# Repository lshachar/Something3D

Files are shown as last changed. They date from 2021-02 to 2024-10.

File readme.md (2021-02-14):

Check out this very detailed video I made [here](https://youtu.be/JVCmWvRvEYM).  
(It's in Hebrew... I Don't think anyone outside of Israel have ever heard about this 3D printer company.)  
I bought mine in 2013 and it worked awfully until 2021, when I fixed all the issues it had.  
The purpose of this git is to help owners of a Something3D printer to make it into a usable machine!    

If you'd like to update your Marlin Firmware, and use my settings,  
Download [Marlin 2.0.1](https://github.com/MarlinFirmware/Marlin/releases/tag/2.0.1)  
Use my Configuration.h & Configuration_adv.h files.

If you'd like to use a newer Marlin you can compare (diff) these two files on this github,  
to their original version that you have downloaded.  
Then download a newer Marlin firmware, and edit the two new files with all the necessary changes from my files.

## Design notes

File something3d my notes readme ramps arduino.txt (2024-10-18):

Something3D
02:28 ‎08/‎05/‎2023
בבדיקה עם
PID_OPENLOOP
בכוח מלא (255, שמשום מה מציג לי שהוא מעביר 245)
בגובה 7.5ממ אני מצליח להגיע לטמפ' 210 מעלות, עם מאוורר על 100 אחוז, אבל לא תוך כדי הוצאת פלסטיק.
אז אני מגביל בפרופיל את המאוורר ל80 אחוז בגובה 7.5
(ציפיתי את הראש החם בשכבת סיליקון היום בבוקר)
___________
Parts:

Ramps V1.4 (can be read on board)
screen + sd card reader mj204b (RAMPS GADGETS3D LCD and SHIELD v1.0) http://gadgets3d.com/beta/index.php?route=product/product&product_id=65
gadgets3d fan splitter rev1
Arduino mega 2560
installed stepper motor drivers, on Ramps board: G3D A498 driver rev1
hotbed thermocoupler resistence: 142.7 kOhm
Nozzle on both = 0.35 (according to an old slic3r file from 2013, probably legit)

X max travel 280
Y max travel 270 (but can actually reach 280, if I really need it one day...)
Z max travel 270

3/4 extruder motors: sy42sth47 1206A (except Z)
(060047083 & 1806307 is still also readable on them)

____________

Original Firmware settings:
Control->Temperature
Autotemp off
	Min:210
	Max:250
	Fact:000.10
PID-P: +058.91
PID-I: +004.96
PID-D: +174.70
PID-C: 1

Control->Temperature->Preheat PLA conf
Fan speed:255	(i'm assuming this isn't wired)
Nozzle:200
Bed:60

Control->Temperature->Preheat ABS conf
Nozzle:235 (240 default for marlin firmware)
Bed:105 (110 default for marlin firmware)

Control->Motion
Accel:500
Vxy-jerk: 5
Vz-jerk: +000.10
Ve-jerk: 5
Vmax x: 500
Vmax y: 500
Vmax z: 5
Vmax e: 25
Vmin: 0
VTray min: 0
Amax x: 900
Amax y: 900
Amax z: 5
Amax e: 10000
A-retract: 900
Xsteps/mm: +053.20  ** new: 53.5
Ysteps/mm: +053.20  ** new: 53.5
Zsteps/mm: +1632.0  ** new: 1600
Esteps/mm: +0095.6  ** new: 92.73 for 1st (new) extruder, unknown for 2nd
updated Esteps to 94.18 on 4.5.23.

_____________
A few links that helped me:

https://3dprinting.stackexchange.com/questions/6535/controlling-more-fans-with-ramps-board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

UBL:
https://marlinfw.org/docs/features/unified_bed_leveling.html
https://3dprinting.stackexchange.com/questions/8153/how-to-set-z-probe-boundary-limits-in-firmware-when-using-automatic-bed-leveling
https://github.com/MarlinFirmware/Marlin/issues/9418 

_____________
Notes for self. Testing and calibrating my printer 29.1.2021
100mm at 50mm/min 2nd extruder (left) T1, extruded 105.3mm.
100mm at 50mm/min 1st extruder, extruded 98mm.
why?
anyhow current value is 95.6.
so let's print with 1st extruder, new value 97.551
https://www.e-ci.com/3d-scoop/2020/1/16/calculating-e-steps-extruder-accuracy-in-octoprint

Watching how the cel automaker prints: EVERY layer has a full grid infill. as oppose to: one layer criss, other layer cross. so adhesion must be better!!
Kisslicer is not willing to generate that!
(fill pattern is called 'lines' in automaker, but Cura calls it 'grid'. and it is using Cura for the gcode.

I'm overextruding while the printer is moving - then there's low pressure when it's starting to extrude again.
I can retract at every Z level change and then add 0.64 mm^3 (retraction extra prime amount - cura). looks better.
https://community.ultimaker.com/topic/15459-retraction-extra-prime-amount-suggested-values/

Z max feedrate at 10 was too much! went back to default 5!
50mm movement at Z gives me 51mm!
current steps:1632 per mm.
//fyi:
//10 threads are ~19.5mm
//1mm = 0.5128205128205128 = 1632of Z axis turn (~half a thread)
1632 * 50 / 51 = 1600. seems great!

fml. x axis 130mm was 129.3
053.20 * 130/129.3
new steps: 53.48. 53.5? works great. (assumed x/y are the same. for good reasons though)

new extruder assembly. 
now 100mm extrusion = 105.2, new 92.73, good.

20x20x5 cube *on CEL automaker*:
11.67 seconds for single parameter (hollow)
80/11.67 = 6.85 mm/s
30 seconds for the top layer. 
which is 50 stripes of 0.4mm extrusion. 50x20 = 1000mm total layer length.
1000/30 = 33mm/s for the top layer.

_____________
Some Gcode commands
http://marlinfw.org/meta/gcode/
g92 z0 set home
g90 absolute
g91 relative

g28 - auto home - watch out!
M114 - Get Current Position
M119 - Get endstop state
M211 - software endstops off/on
M226 - wait for pin State.

ניסיון שימוש בפקודה שמחכה ללחיצה על המיקרוסויץ' של הזד שלא עובדת כרגע:
G0 X0
M117 wait for z limit switch to get pressed  (only 20 letters on screen)
M226 P18 S1
G0 X5
M25 ; pause sd print
G0 x0

5.5.23, current m503:
SENDING:M503
echo:  G21    ; Units in mm (mm)
echo:  M149 C ; Units in Celsius
echo:Filament settings: Disabled
echo:  M200 D1.75
echo:  M200 T1 D1.75
echo:  M200 D0
echo:Steps per unit:
echo: M92 X53.50 Y53.50 Z1600.00 E94.18
echo:Maximum feedrates (units/s):
echo:  M203 X500.00 Y500.00 Z5.00 E500.00
echo:Maximum Acceleration (units/s2):
echo:  M201 X500.00 Y500.00 Z100.00 E10000.00
echo:Acceleration (units/s2): P<print_accel> R<retract_accel> T<travel_accel>
echo:  M204 P500.00 R2000.00 T3000.00
echo:Advanced: B<min_segment_time_us> S<min_feedrate> T<min_travel_feedrate> J<junc_dev>
echo:  M205 B20000.00 S0.00 T0.00 J0.01
echo:Home offset:
echo:  M206 X0.00 Y0.00 Z0.00
echo:Hotend offsets:
echo:  M218 T1 X33.30 Y0.00 Z0.000
echo:Unified Bed Leveling:
echo:  M420 S1 Z10.00
Unified Bed Leveling System v1.01 active
Active Mesh Slot: 1
EEPROM can hold 7 meshes.
echo:Material heatup parameters:
echo:  M145 S0 H195 B60 F0
echo:  M145 S1 H235 B105 F0
echo:PID settings:
echo:  M301 P161.35 I24.63 D264.29 F0.00
echo:  M301 P107.71 I13.55 D213.98 F0.00
echo:  M304 P73.68 I7.56 D478.84
echo:Z-Probe Offset (mm):
echo:  M851 X-44.00 Y-4.00 Z7.50
echo:Linear Advance:
echo:  M900 T0 K0.12
  M900 T1 K0.00
echo:Tool-changing:
echo: Z2.00

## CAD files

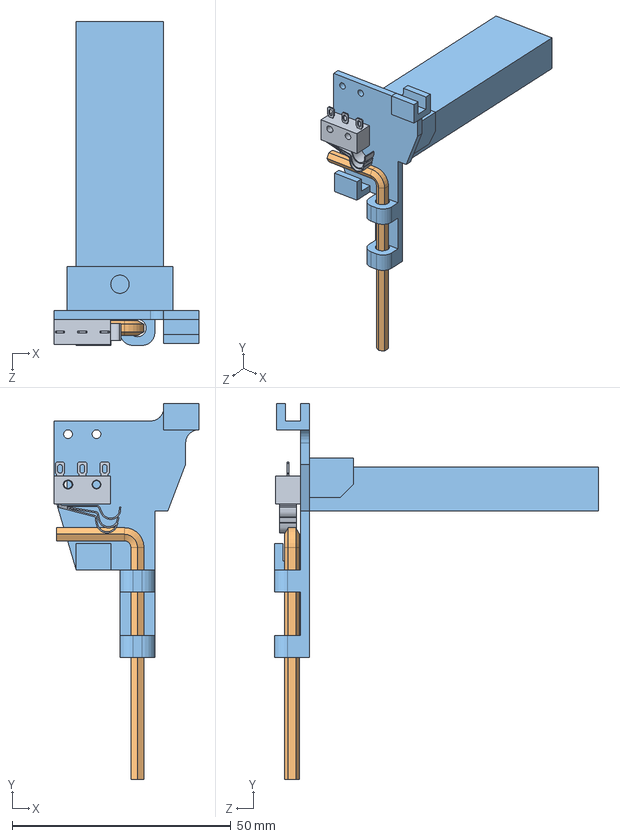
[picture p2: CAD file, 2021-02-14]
ABL Z-Probe/ABL allen.SLDASM
33.0 x 85.9 x 74.0 mm
Microswitch
3mm Allen^ABL allen
ABL stand^ABL allen

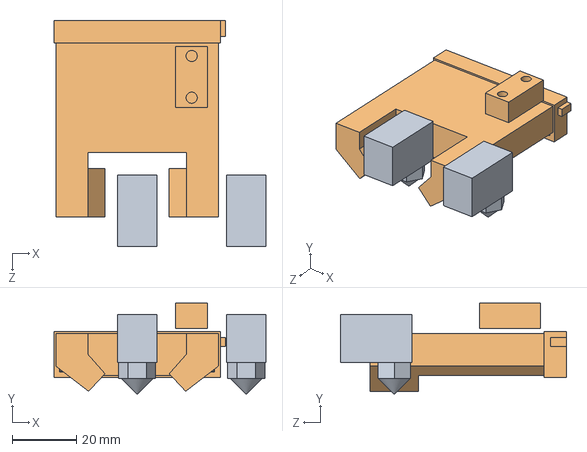
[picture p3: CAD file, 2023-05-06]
something3d fan mount/fan mount.SLDASM
66.1 x 28.3 x 70.3 mm
nozzle x 2
fan mount v4

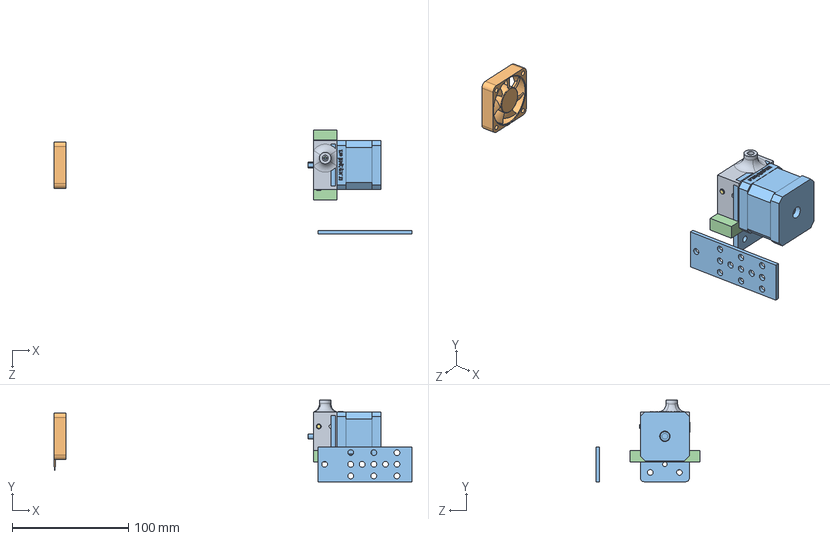
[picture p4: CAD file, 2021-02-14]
extruder v2/something 3d extruder.SLDASM
307.4 x 70.0 x 89.0 mm
Extruder case - v4
nema17 motor
metal bar^something 3d extruder
624z bearing^something 3d extruder
extruder lever - straight V2
hex bolt gradeab_iso

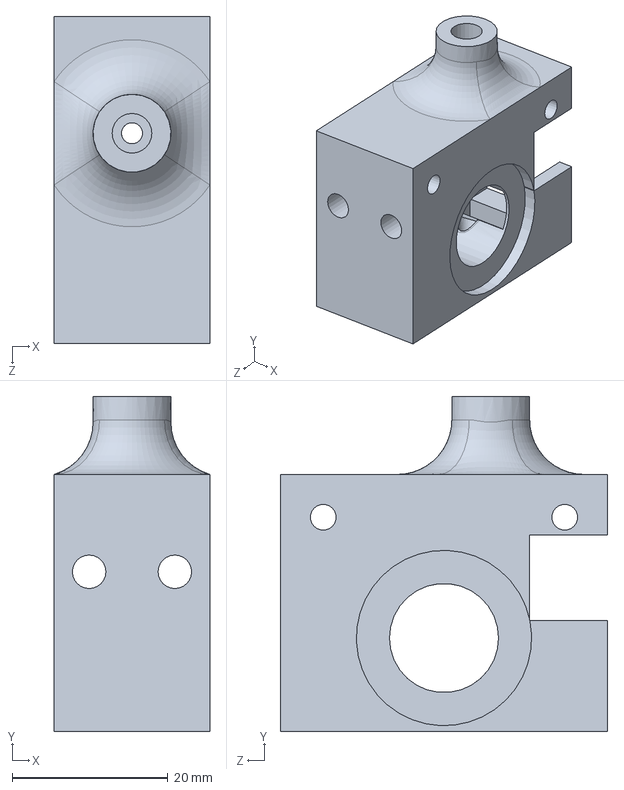
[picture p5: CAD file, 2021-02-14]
extruder v2/Extruder case - v4.SLDPRT
20.0 x 43.0 x 42.0 mm

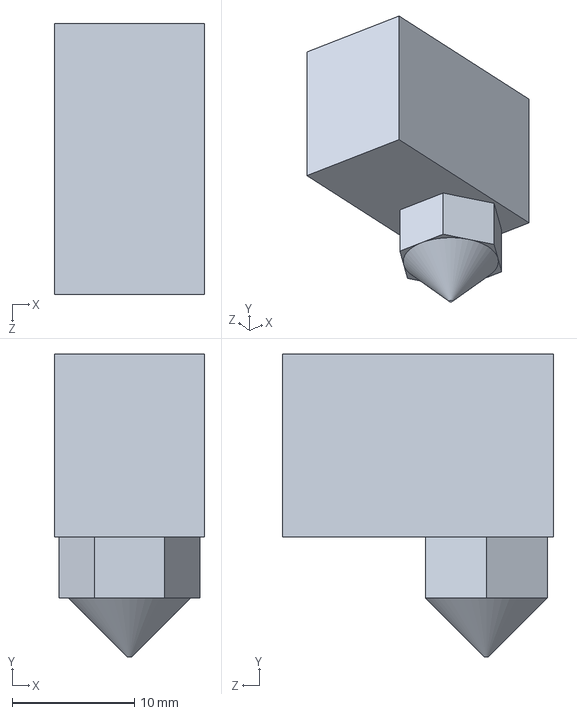
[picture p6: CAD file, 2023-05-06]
something3d fan mount/nozzle.SLDPRT
12.3 x 24.8 x 22.2 mm

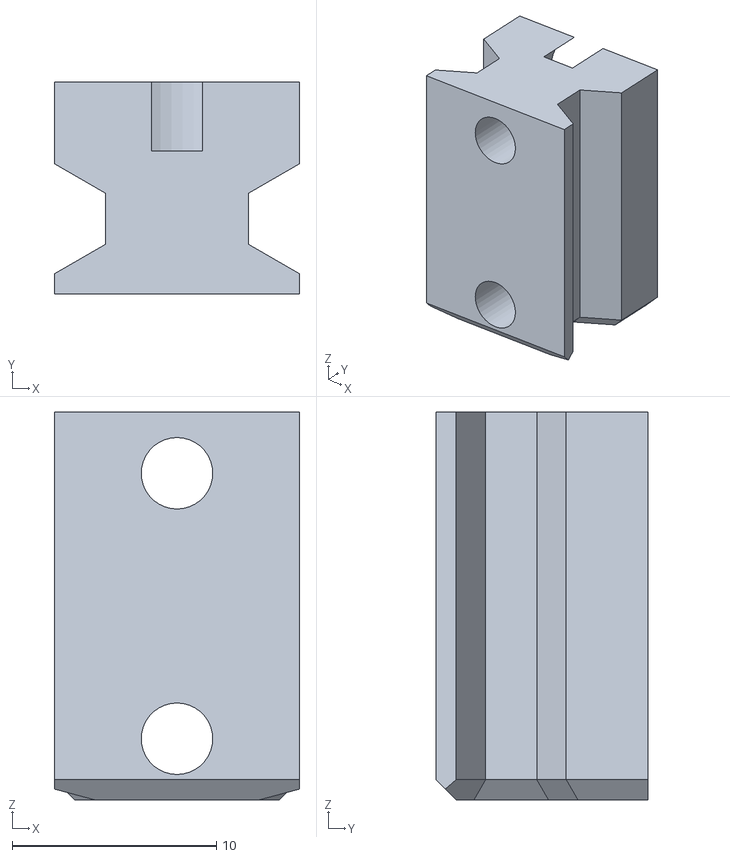
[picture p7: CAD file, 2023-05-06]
something3d fan mount/v4/fan mount v4-printer base.STL
12.0 x 10.4 x 19.0

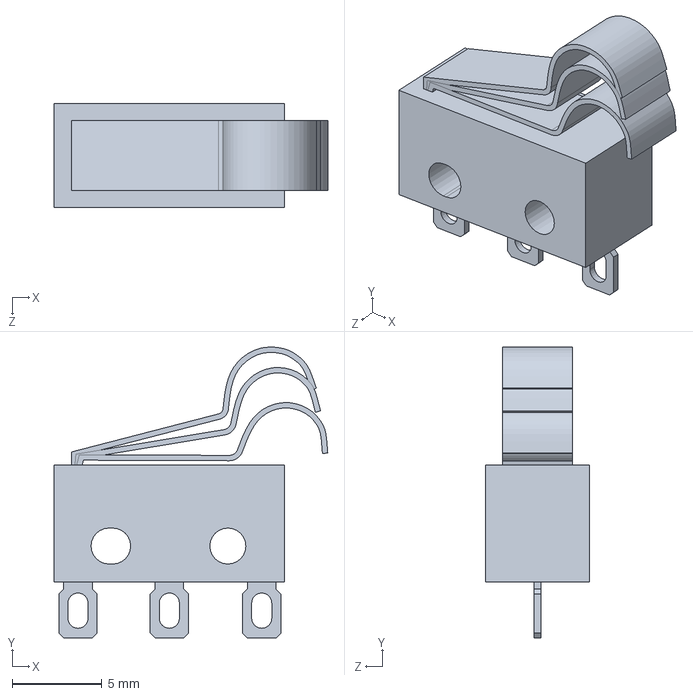
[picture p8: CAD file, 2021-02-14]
ABL Z-Probe/Microswitch.SLDPRT
15.2 x 16.2 x 5.80 mm

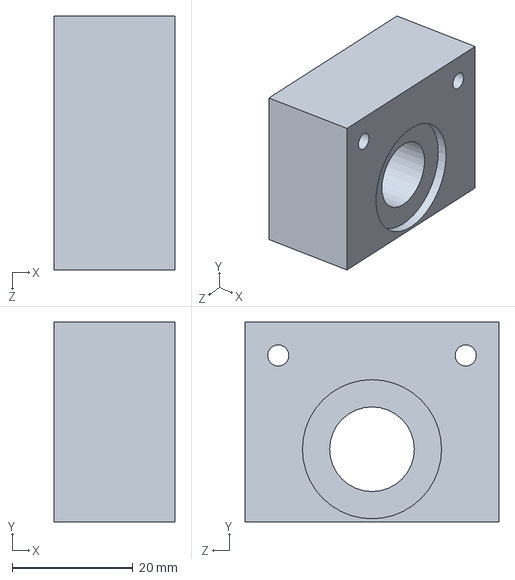
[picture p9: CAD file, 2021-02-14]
extruder v2/Extruder case - original.SLDPRT
20.0 x 33.0 x 42.0 mm

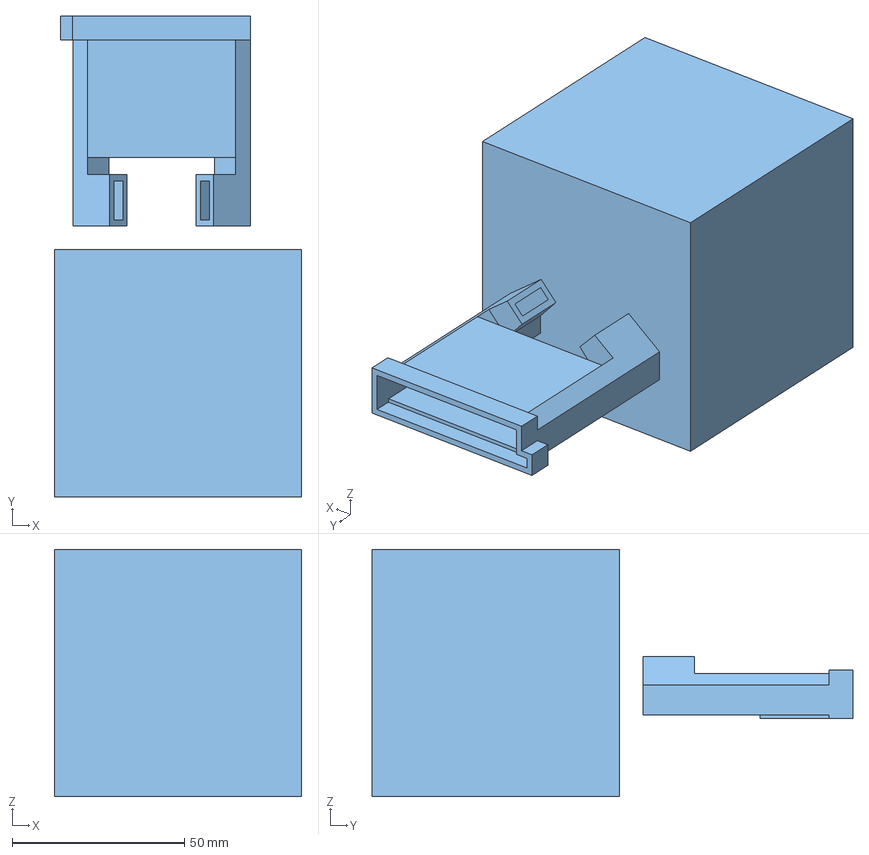
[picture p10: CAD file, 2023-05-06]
something3d fan mount/v4/fan mount v4-fan snap.3mf
71.9 x 139.8 x 71.9 mm
fan mount v4-fan snap.STL
fan mount v4-printer base.STL
fan mount v4-fan mount v4.STL

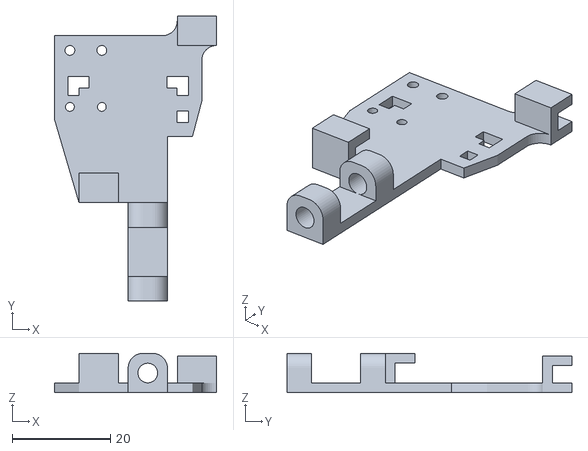
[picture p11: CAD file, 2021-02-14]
ABL Z-Probe/ABL stand^ABL allen-base.STL
33.0 x 58.0 x 8.00

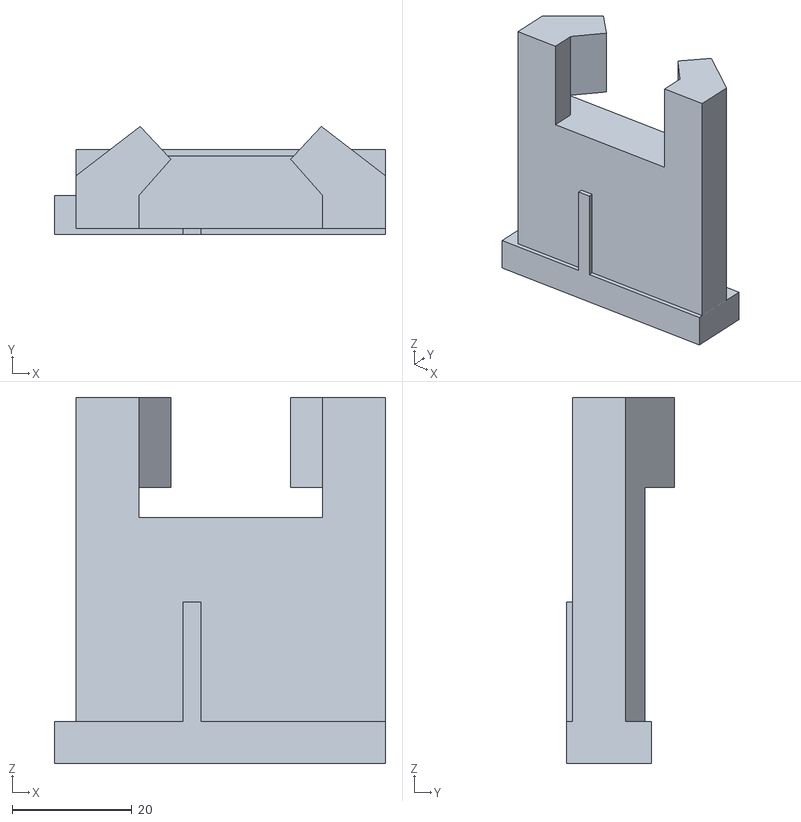
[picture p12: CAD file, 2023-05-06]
something3d fan mount/v4/fan mount v4-fan mount v4.STL
55.3 x 18.0 x 61.1

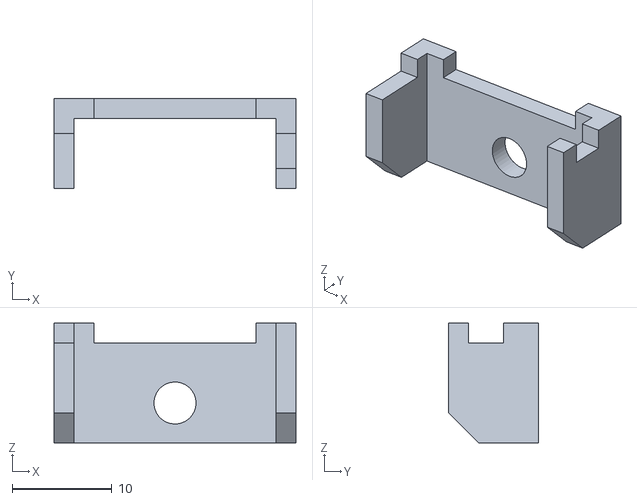
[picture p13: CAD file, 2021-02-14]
ABL Z-Probe/ABL stand^ABL allen-support.STL
24.2 x 9.00 x 12.0

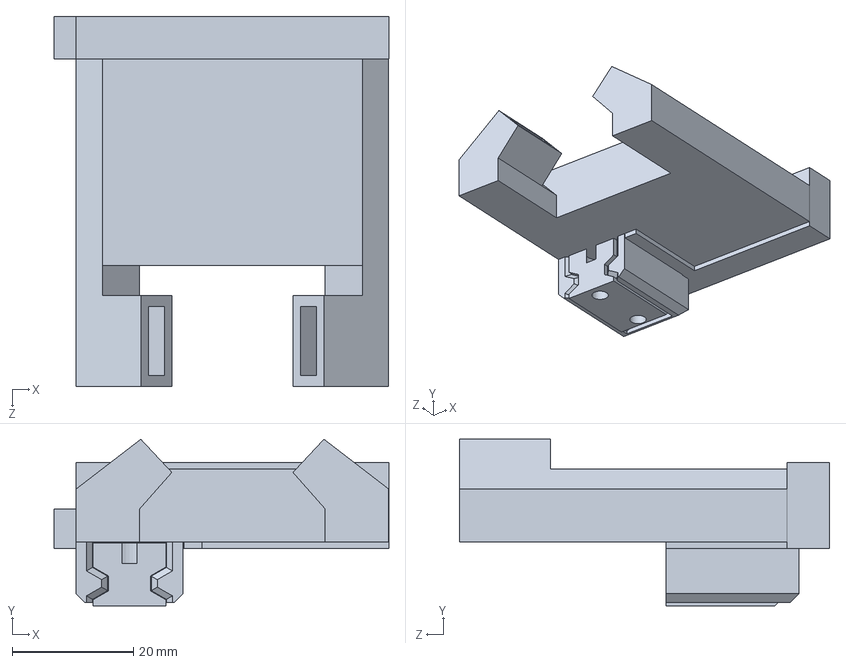
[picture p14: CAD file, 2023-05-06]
something3d fan mount/fan mount v4.SLDPRT
55.3 x 27.5 x 61.1 mm

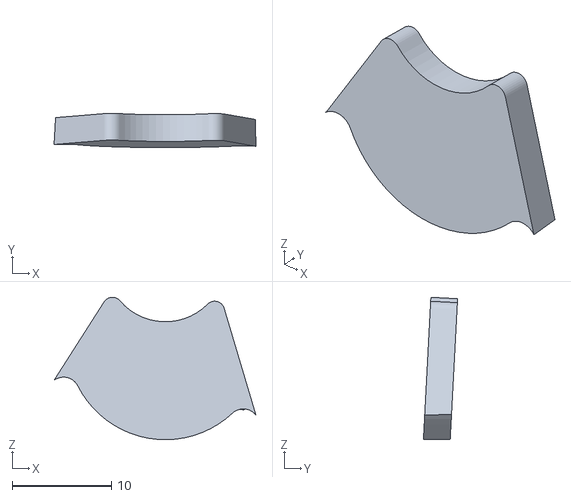
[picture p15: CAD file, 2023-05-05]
something3d fan mount/fan mount-tip.STL
20.4 x 3.45 x 14.4

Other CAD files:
extruder v2/extruder lever - straight V2.SLDPRT
something3d fan mount/fan mount-cap.STL
extruder v2/nema17 motor.SLDPRT
something3d fan mount/fan mount v2 - 3dprint.STL
extruder v2/3mm hex bolt gradeab_iso.sldprt
extruder v2/40x40x10 DC Fan.SLDPRT
extruder v2/4mm hex bolt gradeab_iso.sldprt
extruder v2/Extruder case - v2.SLDPRT
extruder v2/Extruder case - v3.SLDPRT
extruder v2/Extruder case - v3.STL
extruder v2/Extruder case - v4 - mirrored.STL
extruder v2/Extruder case - v4.STL
extruder v2/extruder lever - straight V2.STL
extruder v2/extruder lever - straight.SLDPRT
extruder v2/extruder lever - straight.STL
something3d fan mount/bukoschnozzle-pla-fan-duct.SLDPRT
something3d fan mount/fan mount v2-fan mount support1 test.STL
something3d fan mount/fan mount v2-fan mount support2 test.STL
something3d fan mount/fan mount v2-support - 3dprint.STL
something3d fan mount/fan mount v2.SLDPRT
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

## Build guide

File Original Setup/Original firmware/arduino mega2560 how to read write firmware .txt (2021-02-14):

maybe important:
copy avrdude.conf to same folder as avrdude.exe
seems to work: release reset while pressing return on that command.

avrdude -p atmega2560 -P com18 -c stk500v2 -b115200 -F -U flash:r:something3d_firmware.hex:i
avrdude -p atmega2560 -P com18 -c stk500v2 -b115200 -F -U eeeprom:r:something3d_eeprom.hex:i

to write:
avrdude -p atmega2560 -P com18 -c stk500v2 -b115200 -F -D -U flash:w:firmware.hex:i
avrdude -p atmega2560 -P com18 -c stk500v2 -b115200 -F -D -U eeeprom:w:something3d_eeprom.hex:i

(-did not try writing yet.)

for arduino uno (atmega328p) seems like this should work:
avrdude -p m328P -P com10 -c avrispmkII -b 115200 -F -U eeprom:r:test_eeprom.hex:i
but it doesn't. maybe because it's a chinese clone. maybe the bootloader is ld (avrispmkII not suitable? but it works from the arduino ide!)

avrdude -p atmega2560 -P com17 -c stk500v2 -b115200 -F -D -U flash:w:something3d_firmware.hex:i

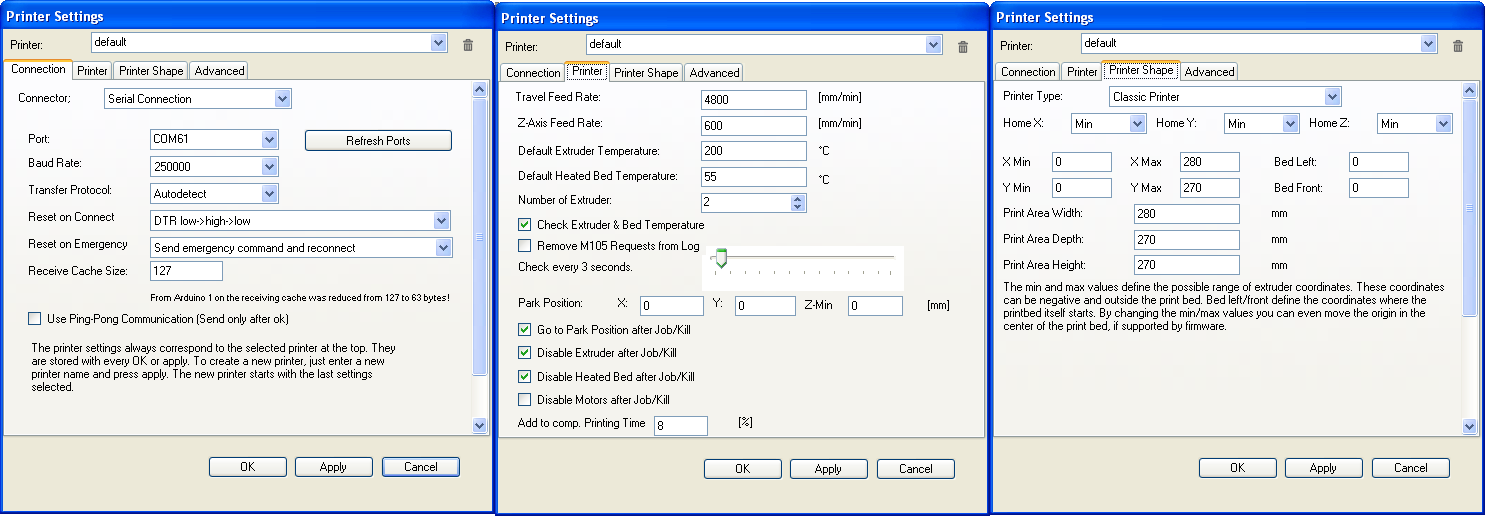
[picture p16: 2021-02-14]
Original Setup/Original Settings/Something3D_Repetier_setup.PNG

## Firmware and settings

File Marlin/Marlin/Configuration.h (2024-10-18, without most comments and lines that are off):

#pragma once
#define CONFIGURATION_H_VERSION 020000
#define STRING_CONFIG_H_AUTHOR "(Shachar Hagever)" // Who made the changes.
#define SHOW_BOOTSCREEN
#define SERIAL_PORT 0
#define BAUDRATE 250000
  #define MOTHERBOARD BOARD_RAMPS_14_EEB
#define EXTRUDERS 2
#define DEFAULT_NOMINAL_FILAMENT_DIA 1.75
#define HOTEND_OFFSET_X { 0.0, 33.30 } // (mm) relative X-offset for each nozzle
#define TEMP_SENSOR_0 1
#define TEMP_SENSOR_1 1
#define TEMP_SENSOR_2 0
#define TEMP_SENSOR_3 0
#define TEMP_SENSOR_4 0
#define TEMP_SENSOR_5 0
#define TEMP_SENSOR_BED 1
#define TEMP_SENSOR_CHAMBER 0
#define DUMMY_THERMISTOR_998_VALUE 25
#define DUMMY_THERMISTOR_999_VALUE 100
#define MAX_REDUNDANT_TEMP_SENSOR_DIFF 10
#define TEMP_RESIDENCY_TIME     10  // (seconds) Time to wait for hotend to "settle" in M109
#define TEMP_WINDOW              1  // (°C) Temperature proximity for the "temperature reached" timer
#define TEMP_HYSTERESIS          3  // (°C) Temperature proximity considered "close enough" to the target
#define TEMP_BED_RESIDENCY_TIME 10  // (seconds) Time to wait for bed to "settle" in M190
#define TEMP_BED_WINDOW          1  // (°C) Temperature proximity for the "temperature reached" timer
#define TEMP_BED_HYSTERESIS      3  // (°C) Temperature proximity considered "close enough" to the target
#define HEATER_0_MINTEMP   5
#define HEATER_1_MINTEMP   5
#define HEATER_2_MINTEMP   5
#define HEATER_3_MINTEMP   5
#define HEATER_4_MINTEMP   5
#define HEATER_5_MINTEMP   5
#define BED_MINTEMP        5
#define HEATER_0_MAXTEMP 260
#define HEATER_1_MAXTEMP 260
#define HEATER_2_MAXTEMP 260
#define HEATER_3_MAXTEMP 260
#define HEATER_4_MAXTEMP 260
#define HEATER_5_MAXTEMP 260
#define BED_MAXTEMP      135
#define PIDTEMP
#define BANG_MAX 255     // Limits current to nozzle while in bang-bang mode; 255=full current
#define PID_MAX BANG_MAX // Limits current to nozzle while PID is active (see PID_FUNCTIONAL_RANGE below); 255=full current
#define PID_K1 0.95      // Smoothing factor within any PID loop
  #define PID_EDIT_MENU         // Add PID editing to the "Advanced Settings" menu. (~700 bytes of PROGMEM)
  #define PID_DEBUG             // Sends debug data to the serial port.
  #define PID_FUNCTIONAL_RANGE 20 // If the temperature difference between the target temperature and the actual temperature
  #define DEFAULT_Kp 161.35
  #define DEFAULT_Ki 50.00 // 24.63  (27.2 testing double the kI, but it wont work)
  #define DEFAULT_Kd 264.29
#define PIDTEMPBED
#define MAX_BED_POWER 255 // limits duty cycle to bed; 255=full current
  #define DEFAULT_bedKp 100.00
  #define DEFAULT_bedKi 7.5		// this is all that is important really. uncomment #PID_BED_DEBUG and you'll see.
  #define DEFAULT_bedKd 0		// say no to Kd! what's the point in a steady-state system?!
#define PREVENT_COLD_EXTRUSION
#define EXTRUDE_MINTEMP 170
#define PREVENT_LENGTHY_EXTRUDE
#define EXTRUDE_MAXLENGTH 200
#define THERMAL_PROTECTION_HOTENDS // Enable thermal protection for all extruders
#define USE_XMIN_PLUG
#define USE_YMIN_PLUG
#define USE_ZMIN_PLUG
#define USE_ZMAX_PLUG		// changed: used for the ABL sensor
#define ENDSTOPPULLUPS
#define X_MIN_ENDSTOP_INVERTING true  // Set to true to invert the logic of the endstop.
#define Y_MIN_ENDSTOP_INVERTING true  // Set to true to invert the logic of the endstop.
#define Z_MIN_ENDSTOP_INVERTING true  // Set to true to invert the logic of the endstop.
#define X_MAX_ENDSTOP_INVERTING false // Set to true to invert the logic of the endstop.
#define Y_MAX_ENDSTOP_INVERTING false // Set to true to invert the logic of the endstop.
#define Z_MAX_ENDSTOP_INVERTING false // Set to true to invert the logic of the endstop.
#define Z_MIN_PROBE_ENDSTOP_INVERTING false // Set to true to invert the logic of the probe.
#define DEFAULT_AXIS_STEPS_PER_UNIT   { 53.5, 53.5, 1600.0, 94.18}  // { 53.2, 53.2, 1632.0, 95.6 from default something3d }	// I changed the extruder E steps, read in something3d notes.txt file. 29.1.21
#define DEFAULT_MAX_FEEDRATE          { 500, 500, 5, 100}	// { 500, 500, 5, 25 } Tried 10 for Z max feedrate, too much for printer!
#define LIMITED_MAX_FR_EDITING        // Limit edit via M203 or LCD to DEFAULT_MAX_FEEDRATE * 2
  #define MAX_FEEDRATE_EDIT_VALUES    { 1000, 1000, 7, 500 } // ...or, set your own edit limits
#define DEFAULT_MAX_ACCELERATION      { 3000, 3000, 100, 10000 }  // { 3000, 3000, 100, 10000 } are the defaults.
#define LIMITED_MAX_ACCEL_EDITING     // Limit edit via M201 or LCD to DEFAULT_MAX_ACCELERATION * 2
  #define MAX_ACCEL_EDIT_VALUES       { 6000, 6000, 200, 20000 }  // { 6000, 6000, 200, 20000 } are the defaults ...or, set your own edit limits
#define DEFAULT_ACCELERATION          500 // 2000 // 3000   // Slowing down to 500 acc - better corners? // X, Y, Z and E acceleration for printing moves.
#define DEFAULT_RETRACT_ACCELERATION  2000 // 3000 // don't go to crazy at 3000? // E acceleration for retracts
#define DEFAULT_TRAVEL_ACCELERATION   3000 // 3000 // rapid move, no need to slow down. // X, Y, Z acceleration for travel (non printing) moves
#define DEFAULT_EJERK    5.0  // May be used by Linear Advance
  #define JUNCTION_DEVIATION_MM 0.013 // (mm) Distance from real junction edge
#define Z_MIN_PROBE_PIN 19   // Pin 19 is Z_MAX endstop, and it is unused on our Something3d Printer.
#define FIX_MOUNTED_PROBE
#define NOZZLE_TO_PROBE_OFFSET {-44,-4,-6.4}  // I think it should be +6.4 instead of -6.4.  {-44,-4,-7.5}  // if sensor is installed to the right of printhead (x+ y+ direction):{77,4,-6.15} // The example in this file is correct, distance is nozzle to probe, not opposite like the link says. // changed {44+33.3 = 77} // https://3dprinting.stackexchange.com/questions/8153/how-to-set-z-probe-boundary-limits-in-firmware-when-using-automatic-bed-leveling
#define MIN_PROBE_EDGE 0	// look at the comment by tatusah https://github.com/MarlinFirmware/Marlin/issues/15933
#define XY_PROBE_SPEED 8000
#define Z_PROBE_SPEED_FAST HOMING_FEEDRATE_Z
#define Z_PROBE_SPEED_SLOW (Z_PROBE_SPEED_FAST / 2)
#define Z_CLEARANCE_DEPLOY_PROBE   10 // Z Clearance for Deploy/Stow
#define Z_CLEARANCE_BETWEEN_PROBES  5 // Z Clearance between probe points
#define Z_CLEARANCE_MULTI_PROBE     5 // Z Clearance between multiple probes
#define Z_PROBE_LOW_POINT          -2 // Farthest distance below the trigger-point to go before stopping
#define Z_PROBE_OFFSET_RANGE_MIN -20
#define Z_PROBE_OFFSET_RANGE_MAX 20
#define Z_MIN_PROBE_REPEATABILITY_TEST
#define PAUSE_BEFORE_DEPLOY_STOW
#define PROBING_FANS_OFF          // Turn fans off when probing
#define X_ENABLE_ON 0
#define Y_ENABLE_ON 0
#define Z_ENABLE_ON 0
#define E_ENABLE_ON 0 // For all extruders
#define DISABLE_X false
#define DISABLE_Y false
#define DISABLE_Z false
#define DISABLE_E false             // For all extruders
#define DISABLE_INACTIVE_EXTRUDER   // Keep only the active extruder enabled
#define INVERT_X_DIR true
#define INVERT_Y_DIR false
#define INVERT_Z_DIR true
#define INVERT_E0_DIR false
#define INVERT_E1_DIR false
#define INVERT_E2_DIR false
#define INVERT_E3_DIR false
#define INVERT_E4_DIR false
#define INVERT_E5_DIR false
#define Z_HOMING_HEIGHT 4  // (mm) Minimal Z height before homing (G28) for Z clearance above the bed, clamps, ...
#define X_HOME_DIR -1
#define Y_HOME_DIR -1
#define Z_HOME_DIR -1
#define X_BED_SIZE 260  // It can just go to 280 if the Z probe isn't there. (I broke the glass, so using 260 max)
#define Y_BED_SIZE 290  // I don't know why I had 270, when it can really do 290. maybe from the time that I experimented with CNC milling? I don't think so.
#define X_MIN_POS 0
#define Y_MIN_POS 0
#define Z_MIN_POS 0
#define X_MAX_POS X_BED_SIZE
#define Y_MAX_POS Y_BED_SIZE
#define Z_MAX_POS 270
#define MIN_SOFTWARE_ENDSTOPS
  #define MIN_SOFTWARE_ENDSTOP_X
  #define MIN_SOFTWARE_ENDSTOP_Y
  #define MIN_SOFTWARE_ENDSTOP_Z
#define MAX_SOFTWARE_ENDSTOPS
  #define MAX_SOFTWARE_ENDSTOP_X
  #define MAX_SOFTWARE_ENDSTOP_Y
  #define MAX_SOFTWARE_ENDSTOP_Z
  #define SOFT_ENDSTOPS_MENU_ITEM  // Enable/Disable software endstops from the LCD
#define AUTO_BED_LEVELING_UBL	// changed (uncommented)
#define RESTORE_LEVELING_AFTER_G28
  #define ENABLE_LEVELING_FADE_HEIGHT
  #define SEGMENT_LEVELED_MOVES
  #define LEVELED_SEGMENT_LENGTH 5.0 // (mm) Length of all segments (except the last one)
  #define G26_MESH_VALIDATION
    #define MESH_TEST_NOZZLE_SIZE    0.35  // (mm) Diameter of primary nozzle.
    #define MESH_TEST_LAYER_HEIGHT   0.2  // (mm) Default layer height for the G26 Mesh Validation Tool.
    #define MESH_TEST_HOTEND_TEMP  	 195    // (°C) Default nozzle temperature for the G26 Mesh Validation Tool.
    #define MESH_TEST_BED_TEMP       60    // (°C) Default bed temperature for the G26 Mesh Validation Tool.
    #define G26_XY_FEEDRATE          20    // (mm/s) Feedrate for XY Moves for the G26 Mesh Validation Tool.
  #define MESH_INSET 0 	// changed from 1. I don't think we need it for something3d.             // Set Mesh bounds as an inset region of the bed
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

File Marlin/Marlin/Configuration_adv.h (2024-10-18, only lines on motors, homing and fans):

#define E0_AUTO_FAN_PIN -1
#define E1_AUTO_FAN_PIN -1
#define E2_AUTO_FAN_PIN -1
#define E3_AUTO_FAN_PIN -1
#define E4_AUTO_FAN_PIN -1
#define E5_AUTO_FAN_PIN -1
#define CHAMBER_AUTO_FAN_PIN -1
#define X_HOME_BUMP_MM 5
#define Y_HOME_BUMP_MM 5
#define Z_HOME_BUMP_MM 2
#define HOMING_BUMP_DIVISOR { 2, 2, 4 }  // Re-Bump Speed Divisor (Divides the Homing Feedrate)
#define MICROSTEP_MODES { 16, 16, 16, 16, 16, 16 } // [1,2,4,8,16]
#define DIGIPOT_I2C_MOTOR_CURRENTS { 1.0, 1.0, 1.0, 1.0, 1.0, 1.0, 1.0, 1.0 }  //  AZTEEG_X3_PRO
#define LIN_ADVANCE  // uncommented 5.5.23
  #define LIN_ADVANCE_K 0.12    // 5.5.23 found out after a successful test. Unit: mm compression per 1mm/s extruder speed

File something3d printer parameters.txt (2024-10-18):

Printer settings:
X (width)  = 270
Y (Depth)  = 290
Z (Height) = 270
Origin at center = False


Printhead settings:
X min = -20
Y min = -10
X max = 10
Y max = 10
Gantry height = 270


Start Gcode:
G28 ;Home
G1 Z15.0 F6000 ;Move the platform down 15mm
;Prime the extruder
G92 E0
G1 F200 E3
G92 E0


End Gcode:
M104 S0
M140 S0
;Retract the filament
G92 E2
G1 E-2 F300
G28 X0 Y0
M84
M300 P3000	; beep


Extruder 1:
Nozzle size: 0.35
compatible material: 1.75

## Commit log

2021-02-03 Something3d Marlin 2.0.1 Works nicely
    [Configuration.h, Configuration_adv.h]
2021-02-03 able to compile with UBL support
    [Configuration.h]
2021-02-14 UBL works, sensor is to the Right of printhead, and I have the left-side values in a comment. Z value depands on the Z home height, which I've changed., run M502 M500 M501 G29 P1 to clear all EEPROM 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
    [Configuration.h]
2021-02-14 * My notes about the Something3D printer * Original settings from when the printer was bought, and original firmware. * My current Cura settings * my Solidworks design files for: 1. New extruder 2. A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
    [3mm hex bolt gradeab_iso.sldprt, 40x40x10 DC Fan.SLDPRT, 4mm hex bolt gradeab_iso.sldprt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]
2023-05-05 5.5.23 after a decade this printer is actually usable now.
    [Configuration.h, Configuration_adv.h, fan mount v2.SLDPRT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]
2023-05-06 A new fan mount (V4) with two fan ports. for more equal cooling (not blowing bridges over to one side). also, a quick-attachment mount. A lovely progress and a noticeable improvment
    [fan mount v2.SLDPRT, fan mount v3.SLDPRT, fan mount v4-fan mount v4.STL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]
2023-05-06 I'm playing around with these values
    [Configuration_adv.h]

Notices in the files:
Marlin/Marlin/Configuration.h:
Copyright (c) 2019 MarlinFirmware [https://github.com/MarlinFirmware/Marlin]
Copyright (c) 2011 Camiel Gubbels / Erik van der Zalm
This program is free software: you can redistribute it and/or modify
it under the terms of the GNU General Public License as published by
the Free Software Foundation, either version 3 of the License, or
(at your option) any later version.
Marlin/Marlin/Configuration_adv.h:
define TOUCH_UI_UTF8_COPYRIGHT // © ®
